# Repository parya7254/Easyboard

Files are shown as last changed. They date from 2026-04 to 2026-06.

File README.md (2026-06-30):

# Easyboard
A hot swappable tenkeyless (full size but without the number pad) mechanical keyboard with RGB lighting and an OLED (SSD1306) display! It will use a RP2040 Pro Micro as the controller, SK6812-MINI-E (reverse mount) LEDs for the backlight, and MX-style switches (and also MX-style hot swap sockets).





# Why did I Make This??
I really like designing my own things, like REALLY. And I also REALLY want a mechanical keyboard. So I thought to myself, *why not just make your own?* So I did one of my most complex projects ever, designing and building my own hot-swappable keyboard with RGB lights. And after about *more than* 60 **MIND GRUELING** hours of work, I managed to finally make a mechanical keyboard, one that was made by **me** and **me** only. And another reason for making this keyboard is that I have a lot of school work which requires a lot of typing and sometimes I write a lot of code, so this keyboard will help me work more efficiently.

# How did I Make This??
All of the PCB designing was done in KiCad and the case was designed in Fusion360. I started with a scematic and layed out my parts like so: 



And after that, I placed my parts on the PCB and then wired them:



The hardest part of designing this keyboard was wiring the things together in my PCB, expecially the LEDs. I ran into many rabbit holes during this process since lots of things were in the way and there was not encough space to wire some things so I had to move some traces and sometimes entirely rewire some things just so I can wire other things. Designing the keyboard made me want to give up and scrap everything and start another project, but I still continued and managed to finish everything.

# BOM
These are the parts that I need to build and assemble my PCB:

| Name | Purpose | Quantity | Total Cost (USD) | Link | Distributor |
|---|---|---|---|---|---|
| SSD1306 OLED Display | This will be the display on my keyboard. I currently plan on having it display the mode of the right 9 extra switches. | 1 | 2.50 | https://www.aliexpress.us/item/3256805954920554.html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 | AliExpress |
| MX Stabilizers | These will be the stabilizers for the longer keys on my keyboard. This will ensure that the longer keycaps properly press when not pressed from the middle. | 1 | 2.86 | https://www.aliexpress.us/item/3256807026554334.html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 | AliExpress |
| Blue MX Hotswap Sockets (110pcs) | This will be to sockets which I solder to the PCB and where I insert my keyboard's switches. | 1 | 12.99 | https://www.amazon.com/DUROCK-Mechanical-Keyboard-Switches-Hot-Swap/dp/B0B4W8WFGS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 | Amazon |
| Keyboard PCB | This will be the main part of my keyboard! This is my circuit board with connects the components to the RP2040 Pro Micro. | 5 | 27.00 | https://cart.jlcpcb.com/quote?spm=jlcpcb.Public.2006 | JLCPCB |
| Green Frosted Translucent Clear Keycaps Set | These will be the keycaps for my keyboard! I chose the color green and also they are transparent so that the RGB lights shine though. | 1 | 16.99 | https://www.amazon.com/GUUKEY-Translucent-Shine-Through-Transparency-Mechanical/dp/B0FLK96YHS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 | Amazon |
| SK6812 MINI-E (100pcs) | This will be the RGB LEDs of my keyboard! They are individually addressable as well (each led can have its own color) and they will add great aesthetics to my keyboard. | 1 | 3.49 | https://www.aliexpress.us/item/3256807677321116.html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 | AliExpress |
| RP2040 Pro Micro | This is my keyboard's microcontroller. It will read the key presses from the key matrix and then convert them into key presses and then send keyboard commands to the connected device and it also will control the RGB lighting and the OLED display.. It is basically the ""brain"" of my keyboard. | 1 | 3.82 | https://www.aliexpress.us/item/3256806781060135.html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 | AliExpress |
| EPOMAKER Shadow Black Switches (100pcs) | These are the switches which will be used for my keyboard! | 1 | 19.99 | https://www.amazon.com/EPOMAKER-Mechanical-Switches-Keyboard-Pre-Lubed/dp/B0FYDQZ8HB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 | Amazon |

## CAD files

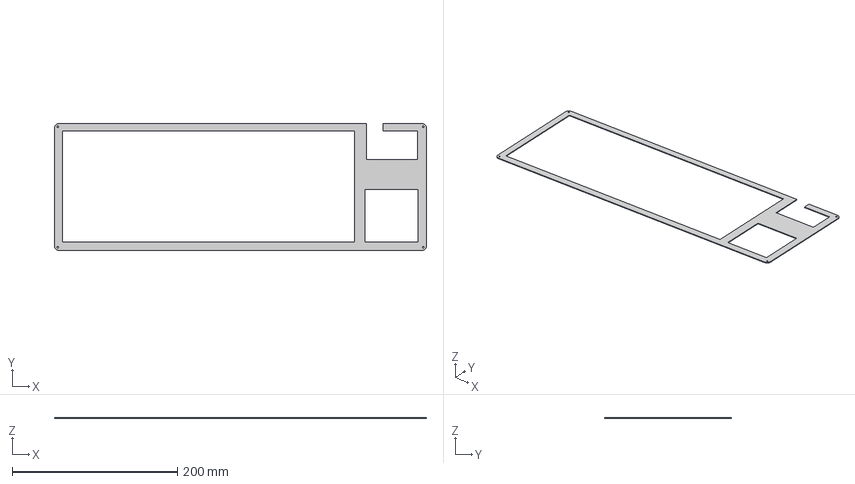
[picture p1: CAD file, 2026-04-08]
CAD/Easyboard-Case-Top.stp
450.8 x 154.5 x 1.00 mm

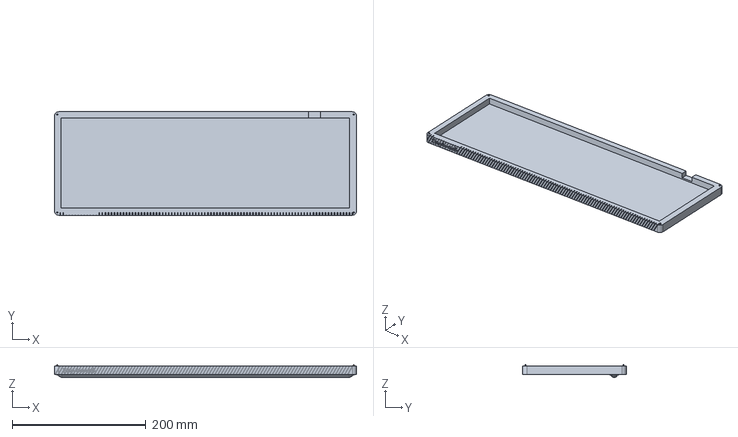
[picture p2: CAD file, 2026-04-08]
CAD/Easyboard-Case.stp
450.8 x 154.5 x 19.0 mm

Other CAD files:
CAD/Easyboard-Case-Top.f3d
CAD/Easyboard-Case.f3d

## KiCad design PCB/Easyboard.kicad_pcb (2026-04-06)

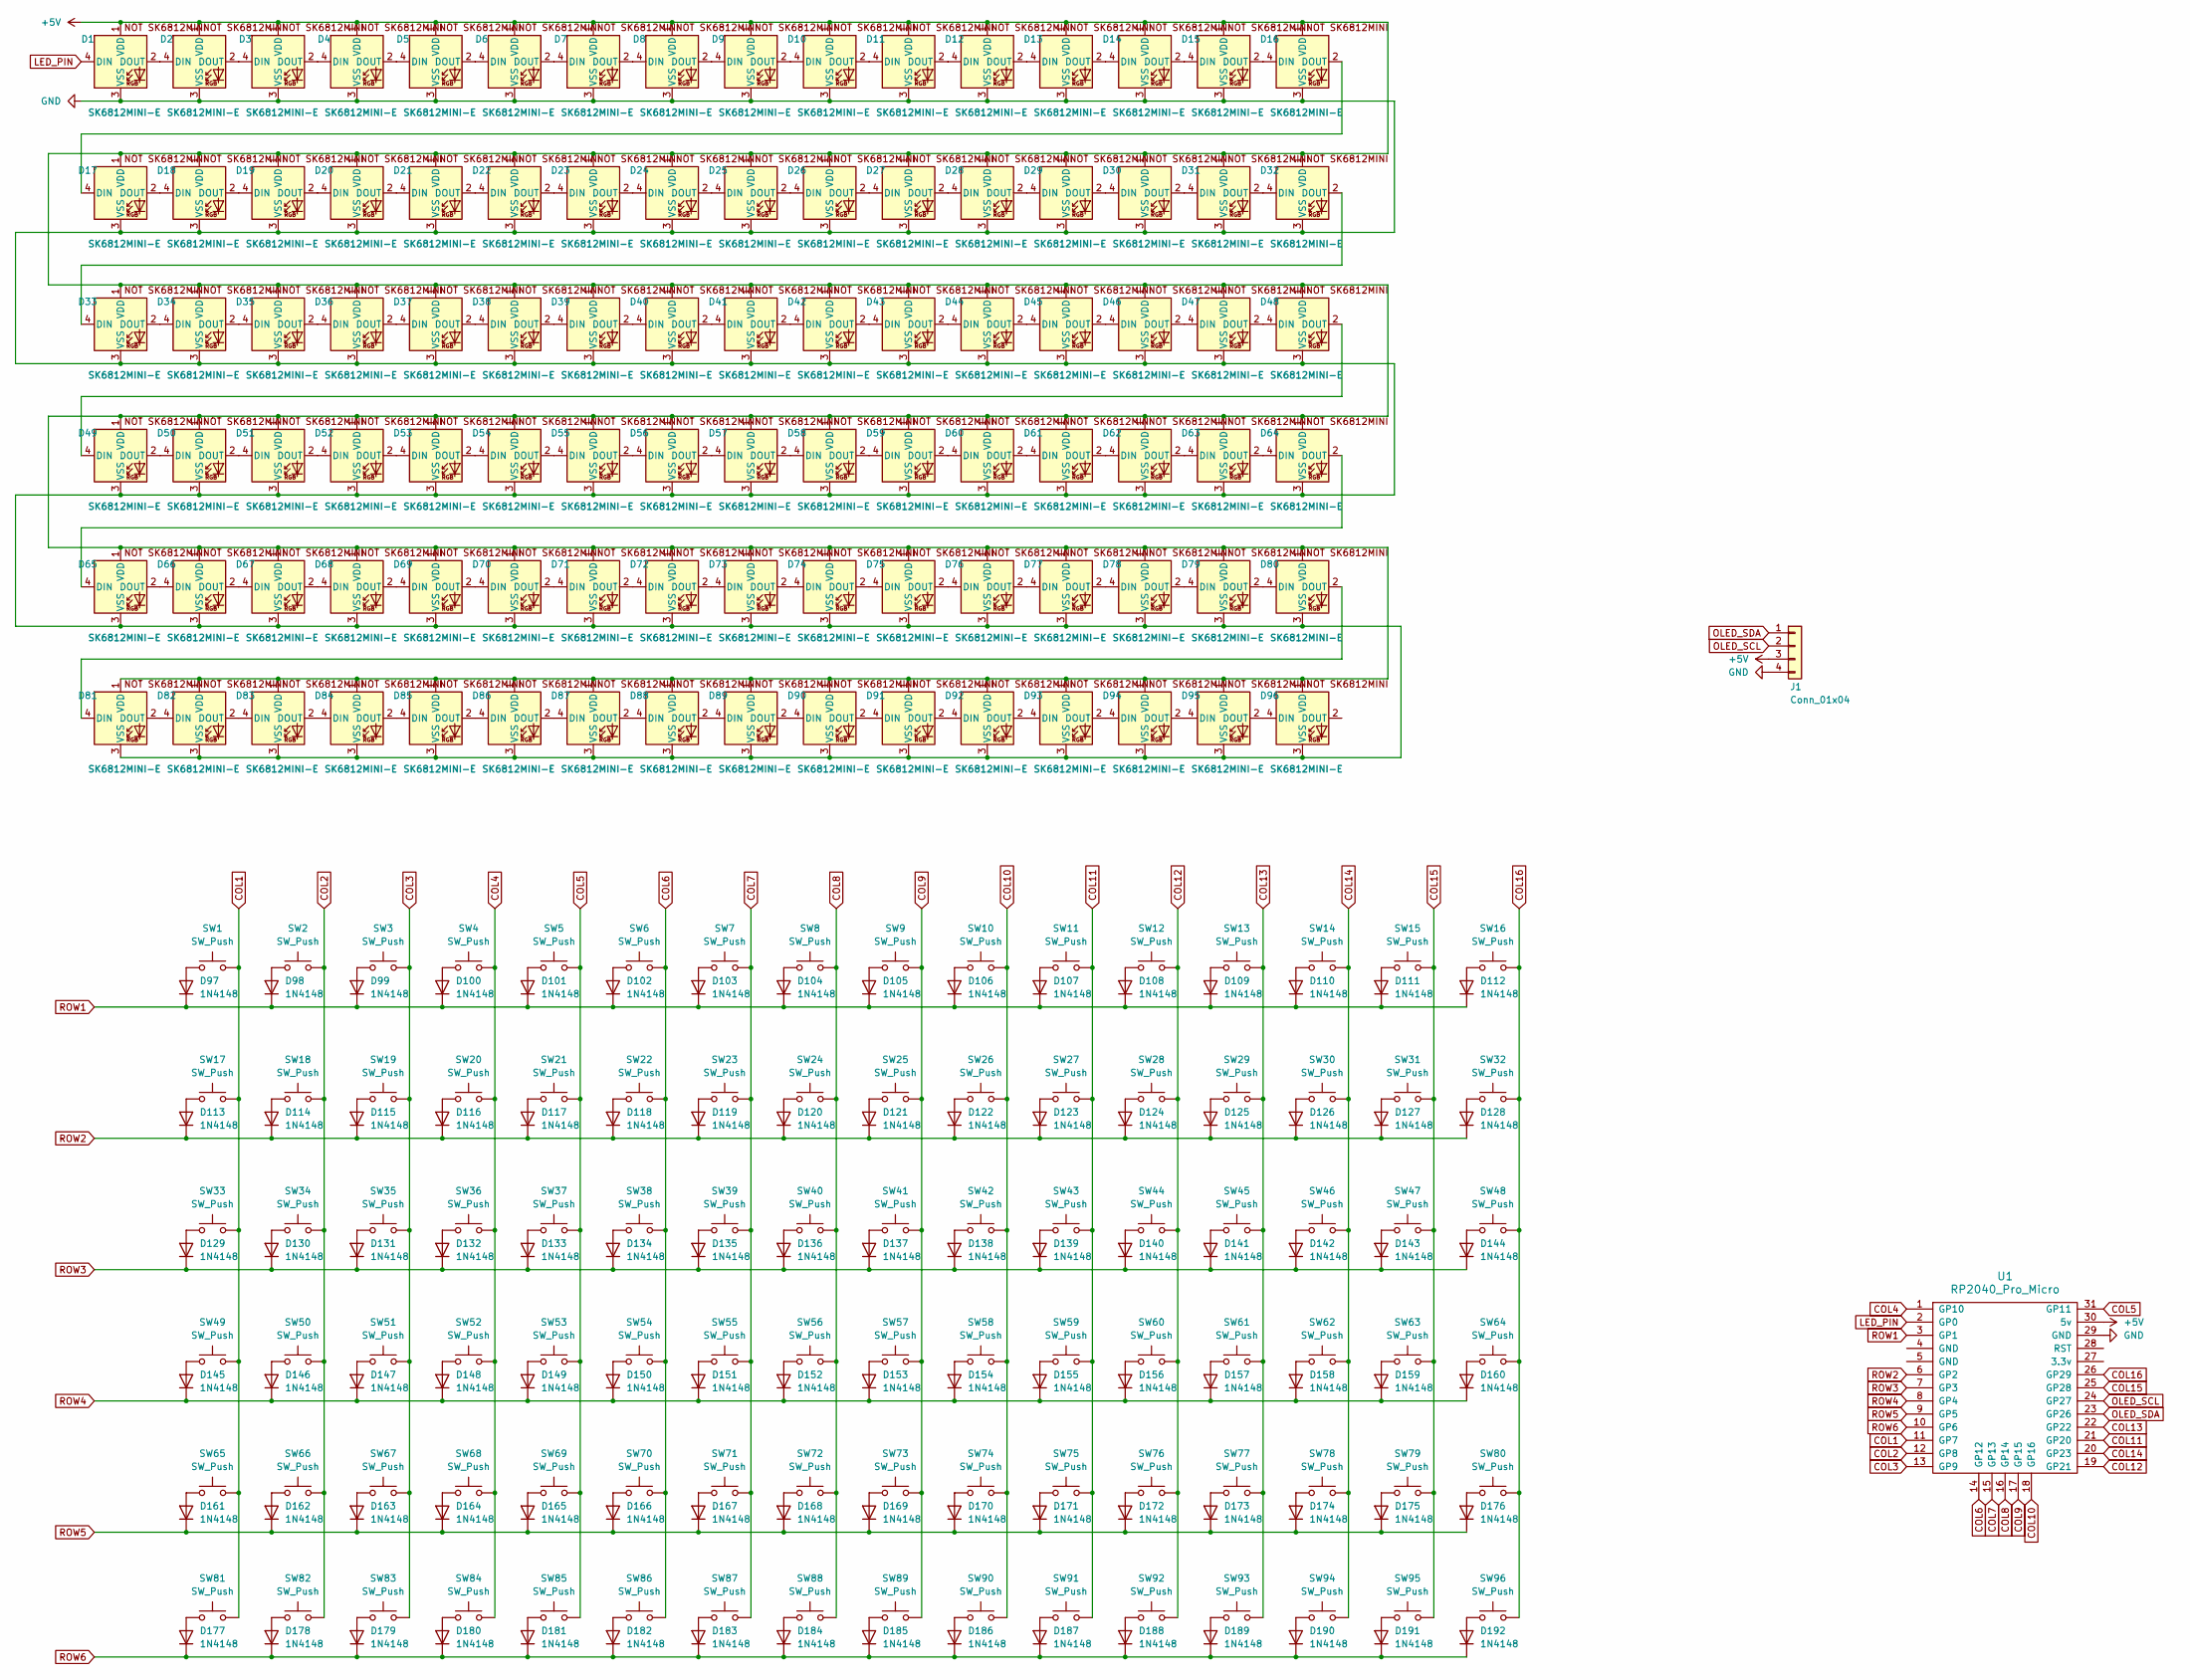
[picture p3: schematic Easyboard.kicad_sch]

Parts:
D1, D2, D3, D4, D5, D6, D7, D8, D9, D10, D11, D12, D13, D14, D15, D16, D17, D18, D19, D20, D21, D22, D23, D24, D25, D26, D27, D28, D29, D30, D31, D32, D33, D34, D35, D36, D37, D38, D39, D40, D41, D42, D43, D44, D45, D46, D47, D48, D49, D50, D51, D52, D53, D54, D55, D56, D57, D58, D59, D60, D61, D62, D63, D64, D65, D66, D67, D68, D69, D70, D71, D72, D73, D74, D75, D76, D77, D78, D79, D80, D81, D82, D83, D84, D85, D86, D87, D88, D89, D90, D91, D92, D93, D94, D95, D96: SK6812MINI-E; MX_SK6812MINI-E_REV
D97, D98, D99, D100, D101, D102, D103, D104, D105, D106, D107, D108, D109, D110, D111, D112, D113, D114, D115, D116, D117, D118, D119, D120, D121, D122, D123, D124, D125, D126, D127, D128, D129, D130, D131, D132, D133, D134, D135, D136, D137, D138, D139, D140, D141, D142, D143, D144, D145, D146, D147, D148, D149, D150, D151, D152, D153, D154, D155, D156, D157, D158, D159, D160, D161, D162, D163, D164, D165, D166, D167, D168, D169, D170, D171, D172, D173, D174, D175, D176, D177, D178, D179, D180, D181, D182, D183, D184, D185, D186, D187, D188, D189, D190, D191, D192: 1N4148; D_DO-35_SOD27_P7.62mm_Horizontal
J1: Conn_01x04; PinHeader_1x04_P2.54mm_Vertical
SW1, SW2, SW3, SW4, SW5, SW6, SW7, SW8, SW9, SW10, SW11, SW12, SW13, SW14, SW15, SW16, SW17, SW18, SW19, SW20, SW21, SW22, SW23, SW24, SW25, SW26, SW27, SW28, SW29, SW31, SW32, SW33, SW35, SW36, SW37, SW38, SW39, SW40, SW41, SW42, SW43, SW44, SW45, SW46, SW48, SW49, SW50, SW52, SW53, SW54, SW55, SW56, SW57, SW58, SW59, SW60, SW61, SW62, SW65, SW66, SW67, SW68, SW69, SW70, SW71, SW72, SW73, SW74, SW76, SW85, SW86, SW87, SW88, SW89, SW90, SW91, SW92, SW93, SW94, SW95, SW96: SW_Push; Hotswap_MX_1.00u
SW30: SW_Push; Hotswap_MX_2.00u
SW34, SW47: SW_Push; Hotswap_MX_1.50u
SW51: SW_Push; Hotswap_MX_1.75u
SW63, SW64: SW_Push; Hotswap_MX_2.25u
SW75: SW_Push; Hotswap_MX_2.75u
SW77, SW78, SW79, SW81, SW82, SW83, SW84: SW_Push; Hotswap_MX_1.25u
SW80: SW_Push; Hotswap_MX_6.25u
U1: RP2040_Pro_Micro

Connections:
+5V: D1.1 (VDD), D2.1 (VDD), D3.1 (VDD), D4.1 (VDD), D5.1 (VDD), D6.1 (VDD), D7.1 (VDD), D8.1 (VDD), D9.1 (VDD), D10.1 (VDD), D11.1 (VDD), D12.1 (VDD), D13.1 (VDD), D14.1 (VDD), D15.1 (VDD), D16.1 (VDD), D17.1 (VDD), D18.1 (VDD), D19.1 (VDD), D20.1 (VDD), D21.1 (VDD), D22.1 (VDD), D23.1 (VDD), D24.1 (VDD), D25.1 (VDD), D26.1 (VDD), D27.1 (VDD), D28.1 (VDD), D29.1 (VDD), D30.1 (VDD), D31.1 (VDD), D32.1 (VDD), D33.1 (VDD), D34.1 (VDD), D35.1 (VDD), D36.1 (VDD), D37.1 (VDD), D38.1 (VDD), D39.1 (VDD), D40.1 (VDD), D41.1 (VDD), D42.1 (VDD), D43.1 (VDD), D44.1 (VDD), D45.1 (VDD), D46.1 (VDD), D47.1 (VDD), D48.1 (VDD), D49.1 (VDD), D50.1 (VDD), D51.1 (VDD), D52.1 (VDD), D53.1 (VDD), D54.1 (VDD), D55.1 (VDD), D56.1 (VDD), D57.1 (VDD), D58.1 (VDD), D59.1 (VDD), D60.1 (VDD), D61.1 (VDD), D62.1 (VDD), D63.1 (VDD), D64.1 (VDD), D65.1 (VDD), D66.1 (VDD), D67.1 (VDD), D68.1 (VDD), D69.1 (VDD), D70.1 (VDD), D71.1 (VDD), D72.1 (VDD), D73.1 (VDD), D74.1 (VDD), D75.1 (VDD), D76.1 (VDD), D77.1 (VDD), D78.1 (VDD), D79.1 (VDD), D80.1 (VDD), D81.1 (VDD), D82.1 (VDD), D83.1 (VDD), D84.1 (VDD), D85.1 (VDD), D86.1 (VDD), D87.1 (VDD), D88.1 (VDD), D89.1 (VDD), D90.1 (VDD), D91.1 (VDD), D92.1 (VDD), D93.1 (VDD), D94.1 (VDD), D95.1 (VDD), D96.1 (VDD), J1.3, U1.30 (5v)
COL1: SW1.2, SW17.2, SW33.2, SW49.2, SW65.2, SW81.2, U1.11 (GP7)
COL2: SW2.2, SW18.2, SW34.2, SW50.2, SW66.2, SW82.2, U1.12 (GP8)
COL3: SW3.2, SW19.2, SW35.2, SW51.2, SW67.2, SW83.2, U1.13 (GP9)
COL4: SW4.2, SW20.2, SW36.2, SW52.2, SW68.2, SW84.2, U1.1 (GP10)
COL5: SW5.2, SW21.2, SW37.2, SW53.2, SW69.2, SW85.2, U1.31 (GP11)
COL6: SW6.2, SW22.2, SW38.2, SW54.2, SW70.2, SW86.2, U1.14 (GP12)
COL7: SW7.2, SW23.2, SW39.2, SW55.2, SW71.2, SW87.2, U1.15 (GP13)
COL8: SW8.2, SW24.2, SW40.2, SW56.2, SW72.2, SW88.2, U1.16 (GP14)
COL9: SW9.2, SW25.2, SW41.2, SW57.2, SW73.2, SW89.2, U1.17 (GP15)
COL10: SW10.2, SW26.2, SW42.2, SW58.2, SW74.2, SW90.2, U1.18 (GP16)
COL11: SW11.2, SW27.2, SW43.2, SW59.2, SW75.2, SW91.2, U1.21 (GP20)
COL12: SW12.2, SW28.2, SW44.2, SW60.2, SW76.2, SW92.2, U1.19 (GP21)
COL13: SW13.2, SW29.2, SW45.2, SW61.2, SW77.2, SW93.2, U1.22 (GP22)
COL14: SW14.2, SW30.2, SW46.2, SW62.2, SW78.2, SW94.2, U1.20 (GP23)
COL15: SW15.2, SW31.2, SW47.2, SW63.2, SW79.2, SW95.2, U1.25 (GP28)
COL16: SW16.2, SW32.2, SW48.2, SW64.2, SW80.2, SW96.2, U1.26 (GP29)
GND: D1.3 (VSS), D2.3 (VSS), D3.3 (VSS), D4.3 (VSS), D5.3 (VSS), D6.3 (VSS), D7.3 (VSS), D8.3 (VSS), D9.3 (VSS), D10.3 (VSS), D11.3 (VSS), D12.3 (VSS), D13.3 (VSS), D14.3 (VSS), D15.3 (VSS), D16.3 (VSS), D17.3 (VSS), D18.3 (VSS), D19.3 (VSS), D20.3 (VSS), D21.3 (VSS), D22.3 (VSS), D23.3 (VSS), D24.3 (VSS), D25.3 (VSS), D26.3 (VSS), D27.3 (VSS), D28.3 (VSS), D29.3 (VSS), D30.3 (VSS), D31.3 (VSS), D32.3 (VSS), D33.3 (VSS), D34.3 (VSS), D35.3 (VSS), D36.3 (VSS), D37.3 (VSS), D38.3 (VSS), D39.3 (VSS), D40.3 (VSS), D41.3 (VSS), D42.3 (VSS), D43.3 (VSS), D44.3 (VSS), D45.3 (VSS), D46.3 (VSS), D47.3 (VSS), D48.3 (VSS), D49.3 (VSS), D50.3 (VSS), D51.3 (VSS), D52.3 (VSS), D53.3 (VSS), D54.3 (VSS), D55.3 (VSS), D56.3 (VSS), D57.3 (VSS), D58.3 (VSS), D59.3 (VSS), D60.3 (VSS), D61.3 (VSS), D62.3 (VSS), D63.3 (VSS), D64.3 (VSS), D65.3 (VSS), D66.3 (VSS), D67.3 (VSS), D68.3 (VSS), D69.3 (VSS), D70.3 (VSS), D71.3 (VSS), D72.3 (VSS), D73.3 (VSS), D74.3 (VSS), D75.3 (VSS), D76.3 (VSS), D77.3 (VSS), D78.3 (VSS), D79.3 (VSS), D80.3 (VSS), D81.3 (VSS), D82.3 (VSS), D83.3 (VSS), D84.3 (VSS), D85.3 (VSS), D86.3 (VSS), D87.3 (VSS), D88.3 (VSS), D89.3 (VSS), D90.3 (VSS), D91.3 (VSS), D92.3 (VSS), D93.3 (VSS), D94.3 (VSS), D95.3 (VSS), D96.3 (VSS), J1.4, U1.29 (GND)
LED_PIN: D1.4 (DIN), U1.2 (GP0)
unnamed: D1.2 (DOUT), D2.4 (DIN)
unnamed: D2.2 (DOUT), D3.4 (DIN)
unnamed: D3.2 (DOUT), D4.4 (DIN)
unnamed: D4.2 (DOUT), D5.4 (DIN)
unnamed: D5.2 (DOUT), D6.4 (DIN)
unnamed: D6.2 (DOUT), D7.4 (DIN)
unnamed: D7.2 (DOUT), D8.4 (DIN)
unnamed: D8.2 (DOUT), D9.4 (DIN)
unnamed: D9.2 (DOUT), D10.4 (DIN)
unnamed: D10.2 (DOUT), D11.4 (DIN)
unnamed: D11.2 (DOUT), D12.4 (DIN)
unnamed: D12.2 (DOUT), D13.4 (DIN)
unnamed: D13.2 (DOUT), D14.4 (DIN)
unnamed: D14.2 (DOUT), D15.4 (DIN)
unnamed: D15.2 (DOUT), D16.4 (DIN)
unnamed: D16.2 (DOUT), D17.4 (DIN)
unnamed: D17.2 (DOUT), D18.4 (DIN)
unnamed: D18.2 (DOUT), D19.4 (DIN)
unnamed: D19.2 (DOUT), D20.4 (DIN)
unnamed: D20.2 (DOUT), D21.4 (DIN)
unnamed: D21.2 (DOUT), D22.4 (DIN)
unnamed: D22.2 (DOUT), D23.4 (DIN)
unnamed: D23.2 (DOUT), D24.4 (DIN)
unnamed: D24.2 (DOUT), D25.4 (DIN)
unnamed: D25.2 (DOUT), D26.4 (DIN)
unnamed: D26.2 (DOUT), D27.4 (DIN)
unnamed: D27.2 (DOUT), D28.4 (DIN)
unnamed: D28.2 (DOUT), D29.4 (DIN)
unnamed: D29.2 (DOUT), D30.4 (DIN)
unnamed: D30.2 (DOUT), D31.4 (DIN)
unnamed: D31.2 (DOUT), D32.4 (DIN)
unnamed: D32.2 (DOUT), D33.4 (DIN)
unnamed: D33.2 (DOUT), D34.4 (DIN)
unnamed: D34.2 (DOUT), D35.4 (DIN)
unnamed: D35.2 (DOUT), D36.4 (DIN)
unnamed: D36.2 (DOUT), D37.4 (DIN)
unnamed: D37.2 (DOUT), D38.4 (DIN)
unnamed: D38.2 (DOUT), D39.4 (DIN)
unnamed: D39.2 (DOUT), D40.4 (DIN)
unnamed: D40.2 (DOUT), D41.4 (DIN)
unnamed: D41.2 (DOUT), D42.4 (DIN)
unnamed: D42.2 (DOUT), D43.4 (DIN)
unnamed: D43.2 (DOUT), D44.4 (DIN)
unnamed: D44.2 (DOUT), D45.4 (DIN)
unnamed: D45.2 (DOUT), D46.4 (DIN)
unnamed: D46.2 (DOUT), D47.4 (DIN)
unnamed: D47.2 (DOUT), D48.4 (DIN)
unnamed: D48.2 (DOUT), D49.4 (DIN)
unnamed: D49.2 (DOUT), D50.4 (DIN)
unnamed: D50.2 (DOUT), D51.4 (DIN)
unnamed: D51.2 (DOUT), D52.4 (DIN)
unnamed: D52.2 (DOUT), D53.4 (DIN)
unnamed: D53.2 (DOUT), D54.4 (DIN)
unnamed: D54.2 (DOUT), D55.4 (DIN)
unnamed: D55.2 (DOUT), D56.4 (DIN)
unnamed: D56.2 (DOUT), D57.4 (DIN)
unnamed: D57.2 (DOUT), D58.4 (DIN)
unnamed: D58.2 (DOUT), D59.4 (DIN)
unnamed: D59.2 (DOUT), D60.4 (DIN)
unnamed: D60.2 (DOUT), D61.4 (DIN)
unnamed: D61.2 (DOUT), D62.4 (DIN)
unnamed: D62.2 (DOUT), D63.4 (DIN)
unnamed: D63.2 (DOUT), D64.4 (DIN)
unnamed: D64.2 (DOUT), D65.4 (DIN)
unnamed: D65.2 (DOUT), D66.4 (DIN)
unnamed: D66.2 (DOUT), D67.4 (DIN)
unnamed: D67.2 (DOUT), D68.4 (DIN)
unnamed: D68.2 (DOUT), D69.4 (DIN)
unnamed: D69.2 (DOUT), D70.4 (DIN)
unnamed: D70.2 (DOUT), D71.4 (DIN)
unnamed: D71.2 (DOUT), D72.4 (DIN)
unnamed: D72.2 (DOUT), D73.4 (DIN)
unnamed: D73.2 (DOUT), D74.4 (DIN)
unnamed: D74.2 (DOUT), D75.4 (DIN)
unnamed: D75.2 (DOUT), D76.4 (DIN)
unnamed: D76.2 (DOUT), D77.4 (DIN)
unnamed: D77.2 (DOUT), D78.4 (DIN)
unnamed: D78.2 (DOUT), D79.4 (DIN)
unnamed: D79.2 (DOUT), D80.4 (DIN)
unnamed: D80.2 (DOUT), D81.4 (DIN)
unnamed: D81.2 (DOUT), D82.4 (DIN)
unnamed: D82.2 (DOUT), D83.4 (DIN)
unnamed: D83.2 (DOUT), D84.4 (DIN)
unnamed: D84.2 (DOUT), D85.4 (DIN)
unnamed: D85.2 (DOUT), D86.4 (DIN)
unnamed: D86.2 (DOUT), D87.4 (DIN)
unnamed: D87.2 (DOUT), D88.4 (DIN)
unnamed: D88.2 (DOUT), D89.4 (DIN)
unnamed: D89.2 (DOUT), D90.4 (DIN)
unnamed: D90.2 (DOUT), D91.4 (DIN)
unnamed: D91.2 (DOUT), D92.4 (DIN)
unnamed: D92.2 (DOUT), D93.4 (DIN)
unnamed: D93.2 (DOUT), D94.4 (DIN)
unnamed: D94.2 (DOUT), D95.4 (DIN)
unnamed: D95.2 (DOUT), D96.4 (DIN)
unnamed: D97.2 (A), SW1.1
unnamed: D98.2 (A), SW2.1
unnamed: D99.2 (A), SW3.1
unnamed: D100.2 (A), SW4.1
unnamed: D101.2 (A), SW5.1
unnamed: D102.2 (A), SW6.1
unnamed: D103.2 (A), SW7.1
unnamed: D104.2 (A), SW8.1
unnamed: D105.2 (A), SW9.1
unnamed: D106.2 (A), SW10.1
unnamed: D107.2 (A), SW11.1
unnamed: D108.2 (A), SW12.1
unnamed: D109.2 (A), SW13.1
unnamed: D110.2 (A), SW14.1
unnamed: D111.2 (A), SW15.1
unnamed: D112.2 (A), SW16.1
unnamed: D113.2 (A), SW17.1
unnamed: D114.2 (A), SW18.1
unnamed: D115.2 (A), SW19.1
unnamed: D116.2 (A), SW20.1
unnamed: D117.2 (A), SW21.1
unnamed: D118.2 (A), SW22.1
unnamed: D119.2 (A), SW23.1
unnamed: D120.2 (A), SW24.1
unnamed: D121.2 (A), SW25.1
unnamed: D122.2 (A), SW26.1
unnamed: D123.2 (A), SW27.1
unnamed: D124.2 (A), SW28.1
unnamed: D125.2 (A), SW29.1
unnamed: D126.2 (A), SW30.1
unnamed: D127.2 (A), SW31.1
unnamed: D128.2 (A), SW32.1
unnamed: D129.2 (A), SW33.1
unnamed: D130.2 (A), SW34.1
unnamed: D131.2 (A), SW35.1
unnamed: D132.2 (A), SW36.1
unnamed: D133.2 (A), SW37.1
unnamed: D134.2 (A), SW38.1
unnamed: D135.2 (A), SW39.1
unnamed: D136.2 (A), SW40.1
unnamed: D137.2 (A), SW41.1
unnamed: D138.2 (A), SW42.1
unnamed: D139.2 (A), SW43.1
unnamed: D140.2 (A), SW44.1
unnamed: D141.2 (A), SW45.1
unnamed: D142.2 (A), SW46.1
unnamed: D143.2 (A), SW47.1
unnamed: D144.2 (A), SW48.1
unnamed: D145.2 (A), SW49.1
unnamed: D146.2 (A), SW50.1
unnamed: D147.2 (A), SW51.1
unnamed: D148.2 (A), SW52.1
unnamed: D149.2 (A), SW53.1
unnamed: D150.2 (A), SW54.1
unnamed: D151.2 (A), SW55.1
unnamed: D152.2 (A), SW56.1
unnamed: D153.2 (A), SW57.1
unnamed: D154.2 (A), SW58.1
unnamed: D155.2 (A), SW59.1
unnamed: D156.2 (A), SW60.1
unnamed: D157.2 (A), SW61.1
unnamed: D158.2 (A), SW62.1
unnamed: D159.2 (A), SW63.1
unnamed: D160.2 (A), SW64.1
unnamed: D161.2 (A), SW65.1
unnamed: D162.2 (A), SW66.1
unnamed: D163.2 (A), SW67.1
unnamed: D164.2 (A), SW68.1
unnamed: D165.2 (A), SW69.1
unnamed: D166.2 (A), SW70.1
unnamed: D167.2 (A), SW71.1
unnamed: D168.2 (A), SW72.1
unnamed: D169.2 (A), SW73.1
unnamed: D170.2 (A), SW74.1
unnamed: D171.2 (A), SW75.1
unnamed: D172.2 (A), SW76.1
unnamed: D173.2 (A), SW77.1
unnamed: D174.2 (A), SW78.1
unnamed: D175.2 (A), SW79.1
unnamed: D176.2 (A), SW80.1
unnamed: D177.2 (A), SW81.1
unnamed: D178.2 (A), SW82.1
unnamed: D179.2 (A), SW83.1
unnamed: D180.2 (A), SW84.1
unnamed: D181.2 (A), SW85.1
unnamed: D182.2 (A), SW86.1
unnamed: D183.2 (A), SW87.1
unnamed: D184.2 (A), SW88.1
unnamed: D185.2 (A), SW89.1
unnamed: D186.2 (A), SW90.1
unnamed: D187.2 (A), SW91.1
unnamed: D188.2 (A), SW92.1
unnamed: D189.2 (A), SW93.1
unnamed: D190.2 (A), SW94.1
unnamed: D191.2 (A), SW95.1
unnamed: D192.2 (A), SW96.1
OLED_SCL: J1.2, U1.24 (GP27)
OLED_SDA: J1.1, U1.23 (GP26)
ROW1: D97.1 (K), D98.1 (K), D99.1 (K), D100.1 (K), D101.1 (K), D102.1 (K), D103.1 (K), D104.1 (K), D105.1 (K), D106.1 (K), D107.1 (K), D108.1 (K), D109.1 (K), D110.1 (K), D111.1 (K), D112.1 (K), U1.3 (GP1)
ROW2: D113.1 (K), D114.1 (K), D115.1 (K), D116.1 (K), D117.1 (K), D118.1 (K), D119.1 (K), D120.1 (K), D121.1 (K), D122.1 (K), D123.1 (K), D124.1 (K), D125.1 (K), D126.1 (K), D127.1 (K), D128.1 (K), U1.6 (GP2)
ROW3: D129.1 (K), D130.1 (K), D131.1 (K), D132.1 (K), D133.1 (K), D134.1 (K), D135.1 (K), D136.1 (K), D137.1 (K), D138.1 (K), D139.1 (K), D140.1 (K), D141.1 (K), D142.1 (K), D143.1 (K), D144.1 (K), U1.7 (GP3)
ROW4: D145.1 (K), D146.1 (K), D147.1 (K), D148.1 (K), D149.1 (K), D150.1 (K), D151.1 (K), D152.1 (K), D153.1 (K), D154.1 (K), D155.1 (K), D156.1 (K), D157.1 (K), D158.1 (K), D159.1 (K), D160.1 (K), U1.8 (GP4)
ROW5: D161.1 (K), D162.1 (K), D163.1 (K), D164.1 (K), D165.1 (K), D166.1 (K), D167.1 (K), D168.1 (K), D169.1 (K), D170.1 (K), D171.1 (K), D172.1 (K), D173.1 (K), D174.1 (K), D175.1 (K), D176.1 (K), U1.9 (GP5)
ROW6: D177.1 (K), D178.1 (K), D179.1 (K), D180.1 (K), D181.1 (K), D182.1 (K), D183.1 (K), D184.1 (K), D185.1 (K), D186.1 (K), D187.1 (K), D188.1 (K), D189.1 (K), D190.1 (K), D191.1 (K), D192.1 (K), U1.10 (GP6)

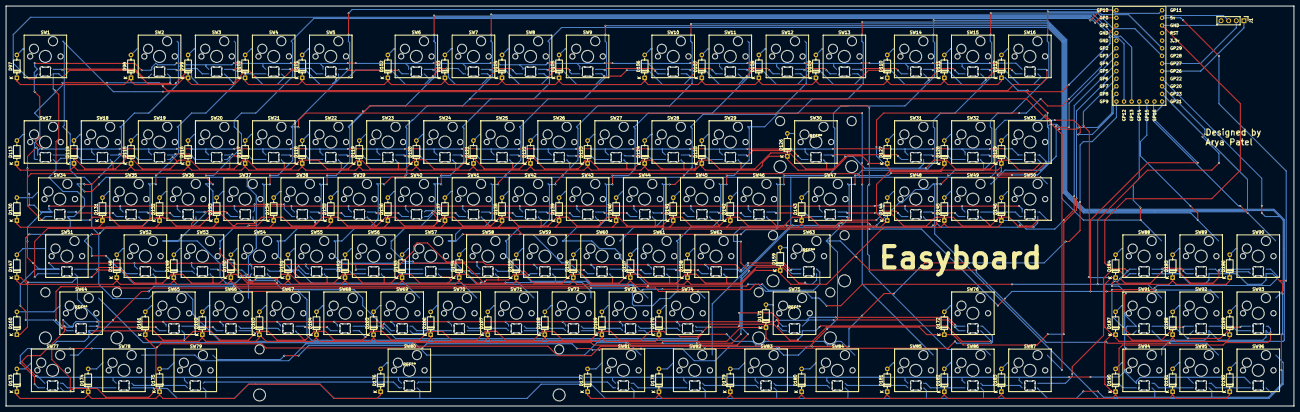
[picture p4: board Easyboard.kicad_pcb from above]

Board: 2 copper layers, 429.8 x 133.5 mm, 290 parts (0 on the bottom side), 218 nets.

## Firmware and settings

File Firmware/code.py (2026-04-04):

import board
import busio
from kmk.kmk_keyboard import KMKKeyboard
from kmk.keys import KC
from kmk.scanners import DiodeOrientation
from kmk.modules.macros import Press, Release, Tap, Macros, Delay
from kmk.extensions.rgb import RGB
from kmk.modules.layers import Layers
from kmk.extensions.display import Display, TextEntry
from kmk.extensions.display.ssd1306 import SSD1306
from kmk.modules.mouse_keys import MouseKeys

keyboard = KMKKeyboard()

mousekeys = MouseKeys(
    max_speed=10,
    acc_interval=100,
    move_step=0.6
)

keyboard.modules.append(MouseKeys())

keyboard.col_pins=(board.GP7, board.GP8, board.GP9, board.GP10, board.GP11, board.GP12, board.GP13, board.GP14,  board.GP15, board.GP16, board.GP20, board.GP21, board.GP22, board.GP23, board.GP28, board.GP29)
keyboard.row_pins=(board.GP1, board.GP2, board.GP3, board.GP4, board.GP5, board.GP6)
keyboard.diode_orientation=DiodeOrientation.COL2ROW
keyboard.modules.append(Layers())

rgb=RGB(pixel_pin=board.GP0, num_pixels=96)
keyboard.extensions.append(rgb)

i2c_bus = busio.I2C(board.GP27, board.GP26)
diplay_driver=SSD1306(
    i2c=i2c_bus
)

display=Display(
    display=display_driver,
    entries=[
        TextEntry('Mode: ', x=0, y=32, y_anchor='B'),
        TextEntry(text='Key Shortcuts', x=40, y=32, y_anchor='B', layer=0),
        TextEntry(text='Mouse', x=40, y=32, y_anchor='B', layer=1),
        TextEntry(text='RGB Animations', x=40, y=32, y_anchor='B', layer=2),
        TextEntry(text='RGB Controls', x=40, y=32, y_anchor='B', layer=3),
        TextEntry(text='0 1 2 3', x=0, y=4),
        TextEntry(text='0', x=0, y=4, inverted=True, layer=0),
        TextEntry(text='1', x=12, y=4, inverted=True, layer=1),
        TextEntry(text='2', x=12, y=4, inverted=True, layer=2),
        TextEntry(text='3', x=12, y=4, inverted=True, layer=3),
    ],

    width=128,
    height=64,
    dim_time=4,
    dim_target=0,
    off_time=10,
    brightness=1,
)

keyboard.extensions.append(display)

keyboard.modules.append(Macros())

MENU=KC.MACRO(
    Press(KC.LSHIFT)
    Tap(KC.F10)
    Release(KC.SHIFT)
)

COPY = KC.MACRO(
    Press(KC.LCTL),
    Tap(KC.C),
    Release(KC.LCTL)
)

PASTE = KC.MACRO(
    Press(KC.LCTL),
    Tap(KC.V),
    Release(KC.LCTL)
)

CUT = KC.MACRO(
    Press(KC.LCTL),
    Tap(KC.X),
    Release(KC.LCTL)
)

UNDO = KC.MACRO(
    Press(KC.LCTL),
    Tap(KC.Z),
    Release(KC.LCTL)
)
REDO = KC.MACRO(
    Press(KC.LCTL),
    Press(KC.LSFT),
    Tap(KC.Z),
    Release(KC.LSFT),
    Release(KC.LCTL)
)

REDO2 = KC.MACRO(
    Press(KC.LCTL),
    Tap(KC.Y),
    Release(KC.LCTL)
)

NEXTWINDOW = KC.MACRO(
    Press(KC.LALT),
    Tap(KC.TAB),
    Release(KC.LALT)
)

LASTWINDOW = KC.MACRO(
    Press(KC.LALT),
    Press(KC.LSHIFT),
    Tap(KC.TAB),
    Release(KC.LSHIFT),
    Release(KC.LALT)
)

L0= KC.DF(0)
L1= KC.DF(1)
L2= KC.DF(2)
L3= KC.DF(3)

keyboard.keymap = [
    # Layer 0
    {
        KC.ESC, KC.F1, KC.F2, KC.F3, KC.F4, KC.F5, KC.F6, KC.F7, KC.F8, KC.F9, KC.F10, KC.F11, KC.F12, KC.PSCREEN, KC.SCROLLLOCK, KC.PAUSE,
        KC.GRAVE, KC.N1, KC.N2, KC.N3, KC.N4, KC.N5, KC.N6, KC.N7, KC.N8, KC.N9, KC.N0, KC.MINUS, KC.EQUAL, KC.BSPACE, KC.INSERT, KC.HOME,
        KC.PGUP, KC.TAB, KC.Q, KC.W, KC.E, KC.T, KC.Y, KC.U, KC.U, KC.I, KC.O, KC.P, KC.LBRACKET, KC.RBRACKET, KC.BSLASH, KC.DELETE,
        KC.END, KC.PGDOWN, KC.CAPSLOCK, KC.A, KC.S, KC.D, KC.F, KC.G, KC.H, KC.J, KC.K, KC.L, KC.SCOLON, KC.QUOTE, KC.ENTER, KC.LSHIFT,
        KC.Z, KC.X, KC.C, KC.V, KC.B KC.N, KC.M, KC.COMMA, KC.DOT, KC.SLASH, KC.RSHIFT, KC.UP, KC.LCTRL, KC.LWIN, KC.LALT, KC.SPACE,
        KC.RALT, KC.RGUI, MENU, KC.RCTRL, KC.LEFT, KC.DOWN, KC.RIGHT, COPY, PASTE, CUT, UNDO, REDO, REDO2, NEXTWINDOW, LASTWINDOW, L1,

    }
    # Layer 1
    {
        KC.ESC, KC.F1, KC.F2, KC.F3, KC.F4, KC.F5, KC.F6, KC.F7, KC.F8, KC.F9, KC.F10, KC.F11, KC.F12, KC.PSCREEN, KC.SCROLLLOCK, KC.PAUSE,
        KC.GRAVE, KC.N1, KC.N2, KC.N3, KC.N4, KC.N5, KC.N6, KC.N7, KC.N8, KC.N9, KC.N0, KC.MINUS, KC.EQUAL, KC.BSPACE, KC.INSERT, KC.HOME,
        KC.PGUP, KC.TAB, KC.Q, KC.W, KC.E, KC.T, KC.Y, KC.U, KC.U, KC.I, KC.O, KC.P, KC.LBRACKET, KC.RBRACKET, KC.BSLASH, KC.DELETE,
        KC.END, KC.PGDOWN, KC.CAPSLOCK, KC.A, KC.S, KC.D, KC.F, KC.G, KC.H, KC.J, KC.K, KC.L, KC.SCOLON, KC.QUOTE, KC.ENTER, KC.LSHIFT,
        KC.Z, KC.X, KC.C, KC.V, KC.B KC.N, KC.M, KC.COMMA, KC.DOT, KC.SLASH, KC.RSHIFT, KC.UP, KC.LCTRL, KC.LWIN, KC.LALT, KC.SPACE,
        KC.RALT, KC.RGUI, MENU, KC.RCTRL, KC.LEFT, KC.DOWN, KC.RIGHT, KC.MB_LMB,  KC.MS_UP,  KC.MB_RMB,  KC.MS_LEFT, KC.MS_DOWN, KC.MS_RIGHT, KC.NO, KC.MS_DOWN, L2,

    }
    # Layer 2
    {
        KC.ESC, KC.F1, KC.F2, KC.F3, KC.F4, KC.F5, KC.F6, KC.F7, KC.F8, KC.F9, KC.F10, KC.F11, KC.F12, KC.PSCREEN, KC.SCROLLLOCK, KC.PAUSE,
        KC.GRAVE, KC.N1, KC.N2, KC.N3, KC.N4, KC.N5, KC.N6, KC.N7, KC.N8, KC.N9, KC.N0, KC.MINUS, KC.EQUAL, KC.BSPACE, KC.INSERT, KC.HOME,
        KC.PGUP, KC.TAB, KC.Q, KC.W, KC.E, KC.T, KC.Y, KC.U, KC.U, KC.I, KC.O, KC.P, KC.LBRACKET, KC.RBRACKET, KC.BSLASH, KC.DELETE,
        KC.END, KC.PGDOWN, KC.CAPSLOCK, KC.A, KC.S, KC.D, KC.F, KC.G, KC.H, KC.J, KC.K, KC.L, KC.SCOLON, KC.QUOTE, KC.ENTER, KC.LSHIFT,
        KC.Z, KC.X, KC.C, KC.V, KC.B KC.N, KC.M, KC.COMMA, KC.DOT, KC.SLASH, KC.RSHIFT, KC.UP, KC.LCTRL, KC.LWIN, KC.LALT, KC.SPACE,
        KC.RALT, KC.RGUI, MENU, KC.RCTRL, KC.LEFT, KC.DOWN, KC.RIGHT, KC.RGB_MODE_SWIRL,  KC.RGB_MODE_KNIGHT,  KC.RGB_MODE_BREATHE_RAINBOW,  KC.RGB_MODE_RAINBOW, KC.RGB_MODE_BREATHE, KC.RGB_MODE_PLAIN, KC.RGB_ANI, KC.RGB_AND, L2,

    }
    # Layer 3
    {
        KC.ESC, KC.F1, KC.F2, KC.F3, KC.F4, KC.F5, KC.F6, KC.F7, KC.F8, KC.F9, KC.F10, KC.F11, KC.F12, KC.PSCREEN, KC.SCROLLLOCK, KC.PAUSE,
        KC.GRAVE, KC.N1, KC.N2, KC.N3, KC.N4, KC.N5, KC.N6, KC.N7, KC.N8, KC.N9, KC.N0, KC.MINUS, KC.EQUAL, KC.BSPACE, KC.INSERT, KC.HOME,
        KC.PGUP, KC.TAB, KC.Q, KC.W, KC.E, KC.T, KC.Y, KC.U, KC.U, KC.I, KC.O, KC.P, KC.LBRACKET, KC.RBRACKET, KC.BSLASH, KC.DELETE,
        KC.END, KC.PGDOWN, KC.CAPSLOCK, KC.A, KC.S, KC.D, KC.F, KC.G, KC.H, KC.J, KC.K, KC.L, KC.SCOLON, KC.QUOTE, KC.ENTER, KC.LSHIFT,
        KC.Z, KC.X, KC.C, KC.V, KC.B KC.N, KC.M, KC.COMMA, KC.DOT, KC.SLASH, KC.RSHIFT, KC.UP, KC.LCTRL, KC.LWIN, KC.LALT, KC.SPACE,
        KC.RALT, KC.RGUI, MENU, KC.RCTRL, KC.LEFT, KC.DOWN, KC.RIGHT, KC.RGB_TOG, KC.RGB_HUI, KC.RGB_HUD, KC.RGB_SAI, KC.RGB_SAD, KC.RGB_VAI, KC.RGB_VAD, KC.RGB_MODE_PLAIN, L3,

    }
]

if __name__ == '__main__':
    keyboard.go()

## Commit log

2026-04-04 Finished Code!!
    [itsy_bitsy_to_pro_micro.brd, itsy_bitsy_to_pro_micro.sch, kmkpython_ref.tsv]
2026-04-06 Enhance README with project details and BOM
    Added detailed project description, including the rationale for creating the keyboard, design process, and a bill of materials (BOM) with links to components.
2026-04-08 Added Seperate Top and Bottom Case Files
    [Easyboard-Case-Top.f3d, Easyboard-Case-Top.stp, Easyboard-Case.f3d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]
